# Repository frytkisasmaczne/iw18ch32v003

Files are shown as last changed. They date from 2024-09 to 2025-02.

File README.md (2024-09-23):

How to build PlatformIO based project
=====================================

1. [Install PlatformIO Core](https://docs.platformio.org/page/core.html)
2. Download [development platform with examples](https://github.com/Community-PIO-CH32V/platform-ch32v/archive/develop.zip)
3. Extract ZIP archive
4. Run these commands:

```shell
# Change directory to example
$ cd platform-ch32v/examples/blinky-ch32v003fun

# Build project
$ pio run

# Upload firmware
$ pio run --target upload

# Upload firmware for the specific environment
$ pio run -e ch32v003f4p6_evt_r0 --target upload

# Clean build files
$ pio run --target clean
```

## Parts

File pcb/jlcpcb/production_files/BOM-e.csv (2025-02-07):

Comment | Designator | Footprint | LCSC | Quantity
GND | J10 | PinHeader_1x01_P2.54mm_Vertical |  | 1
DC +5V | J8 | PinHeader_1x01_P2.54mm_Vertical |  | 1
DC 15GND | J7 | PinHeader_1x01_P2.54mm_Vertical |  | 1
DC +15V | J6 | PinHeader_1x01_P2.54mm_Vertical |  | 1
BC848 | Q13 | SOT-23 |  | 1
BC856 | Q20 | SOT-23 |  | 1
BC848 | Q23 | SOT-23 |  | 1
470uF 50V | C2 | CP_Radial_D13.0mm_P5.00mm |  | 1
4.7k | R62 | R_0201_0603Metric |  | 1
100 | R23 | R_0201_0603Metric |  | 1
47k | R40 | R_0201_0603Metric |  | 1
100 | R51 | R_0201_0603Metric |  | 1
100 | R11 | R_0201_0603Metric |  | 1
2k | R13 | R_0201_0603Metric |  | 1
BC848 | Q31 | SOT-23 |  | 1
BC848 | Q7 | SOT-23 |  | 1
BC856 | Q30 | SOT-23 |  | 1
4.7k | R58 | R_0201_0603Metric |  | 1
4.7k | R3 | R_0201_0603Metric |  | 1
BC856 | Q6 | SOT-23 |  | 1
Grids and Anodes | J1 | PinHeader_1x17_P2.54mm_Vertical |  | 1
74HC164 | U3 | SSOP-14_5.3x6.2mm_P0.65mm |  | 1
GPS Header | J9 | PinHeader_1x04_P2.54mm_Vertical |  | 1
100 | R55 | R_0201_0603Metric |  | 1
47k | R56 | R_0201_0603Metric |  | 1
4.7k | R38 | R_0201_0603Metric |  | 1
4.7k | R34 | R_0201_0603Metric |  | 1
BC856 | Q8 | SOT-23 |  | 1
4.7k | R14 | R_0201_0603Metric |  | 1
BC848 | Q33 | SOT-23 |  | 1
2k | R21 | R_0201_0603Metric |  | 1
2k | R41 | R_0201_0603Metric |  | 1
BC848 | Q15 | SOT-23 |  | 1
4.7k | R6 | R_0201_0603Metric |  | 1
2k | R9 | R_0201_0603Metric |  | 1
AC 15V | J3 | PinHeader_1x02_P2.54mm_Vertical |  | 1
BC856 | Q22 | SOT-23 |  | 1
BC856 | Q16 | SOT-23 |  | 1
2k | R37 | R_0201_0603Metric |  | 1
BC848 | Q1 | SOT-23 |  | 1
BC856 | Q26 | SOT-23 |  | 1
4.7k | R10 | R_0201_0603Metric |  | 1
47k | R60 | R_0201_0603Metric |  | 1
CH32V003 PROG | J2 | PinHeader_1x04_P2.54mm_Vertical |  | 1
BC856 | Q4 | SOT-23 |  | 1
BC848 | Q9 | SOT-23 |  | 1
BC856 | Q32 | SOT-23 |  | 1
2k | R5 | R_0201_0603Metric |  | 1
BC848 | Q19 | SOT-23 |  | 1
2k | R1 | R_0201_0603Metric |  | 1
100 | R39 | R_0201_0603Metric |  | 1
47k | R28 | R_0201_0603Metric |  | 1
4.7k | R42 | R_0201_0603Metric |  | 1
100 | R19 | R_0201_0603Metric |  | 1
BC856 | Q12 | SOT-23 |  | 1
47k | R36 | R_0201_0603Metric |  | 1
BC856 | Q34 | SOT-23 |  | 1
100 | R59 | R_0201_0603Metric |  | 1
2k | R33 | R_0201_0603Metric |  | 1
2k | R25 | R_0201_0603Metric |  | 1
100 | R31 | R_0201_0603Metric |  | 1
4.7k | R22 | R_0201_0603Metric |  | 1
100 | R15 | R_0201_0603Metric |  | 1
47k | R16 | R_0201_0603Metric |  | 1
47k | R68 | R_0201_0603Metric |  | 1
4.7k | R50 | R_0201_0603Metric |  | 1
4.7k | R30 | R_0201_0603Metric |  | 1
100 | R67 | R_0201_0603Metric |  | 1
100 | R7 | R_0201_0603Metric |  | 1
47k | R48 | R_0201_0603Metric |  | 1
100 | R27 | R_0201_0603Metric |  | 1
BC856 | Q28 | SOT-23 |  | 1
47k | R20 | R_0201_0603Metric |  | 1
47k | R8 | R_0201_0603Metric |  | 1
BC856 | Q24 | SOT-23 |  | 1
AC Filament Middle | J5 | PinHeader_1x01_P2.54mm_Vertical |  | 1
2k | R65 | R_0201_0603Metric |  | 1
100 | R2 | R_0201_0603Metric |  | 1
47k | R32 | R_0201_0603Metric |  | 1
BC848 | Q5 | SOT-23 |  | 1
1N4007 | D1 | D_DO-41_SOD81_P10.16mm_Horizontal |  | 1
BC848 | Q29 | SOT-23 |  | 1
47k | R52 | R_0201_0603Metric |  | 1
100 | R43 | R_0201_0603Metric |  | 1
47k | R4 | R_0201_0603Metric |  | 1
2k | R61 | R_0201_0603Metric |  | 1
2k | R49 | R_0201_0603Metric |  | 1
47k | R44 | R_0201_0603Metric |  | 1
BC848 | Q25 | SOT-23 |  | 1
100 | R63 | R_0201_0603Metric |  | 1
100 | R47 | R_0201_0603Metric |  | 1
47uF 100V | C1 | CP_Radial_D10.0mm_P5.00mm |  | 1
BC848 | Q11 | SOT-23 |  | 1
AC 27V | J4 | PinHeader_1x02_P2.54mm_Vertical |  | 1
BC856 | Q18 | SOT-23 |  | 1
74HC164 | U1 | SSOP-14_5.3x6.2mm_P0.65mm |  | 1
BC848 | Q17 | SOT-23 |  | 1
2k | R53 | R_0201_0603Metric |  | 1
4.7k | R54 | R_0201_0603Metric |  | 1
CH32V003FxPx | U2 | TSSOP-20_4.4x6.5mm_P0.65mm |  | 1
2k | R17 | R_0201_0603Metric |  | 1
BC856 | Q2 | SOT-23 |  | 1
4.7k | R18 | R_0201_0603Metric |  | 1
47k | R12 | R_0201_0603Metric |  | 1
2k | R57 | R_0201_0603Metric |  | 1
4.7k | R26 | R_0201_0603Metric |  | 1
BC848 | Q21 | SOT-23 |  | 1
BC848 | Q3 | SOT-23 |  | 1
2k | R29 | R_0201_0603Metric |  | 1
BC856 | Q10 | SOT-23 |  | 1
GBU4M | D2 | Diode_Bridge_Vishay_GBU |  | 1
BC856 | Q14 | SOT-23 |  | 1
4.7k | R46 | R_0201_0603Metric |  | 1
4.7k | R66 | R_0201_0603Metric |  | 1
100 | R35 | R_0201_0603Metric |  | 1
2k | R45 | R_0201_0603Metric |  | 1
47k | R24 | R_0201_0603Metric |  | 1
BC848 | Q27 | SOT-23 |  | 1
47k | R64 | R_0201_0603Metric |  | 1
GBU4M | D3 | Diode_Bridge_Vishay_GBU |  | 1

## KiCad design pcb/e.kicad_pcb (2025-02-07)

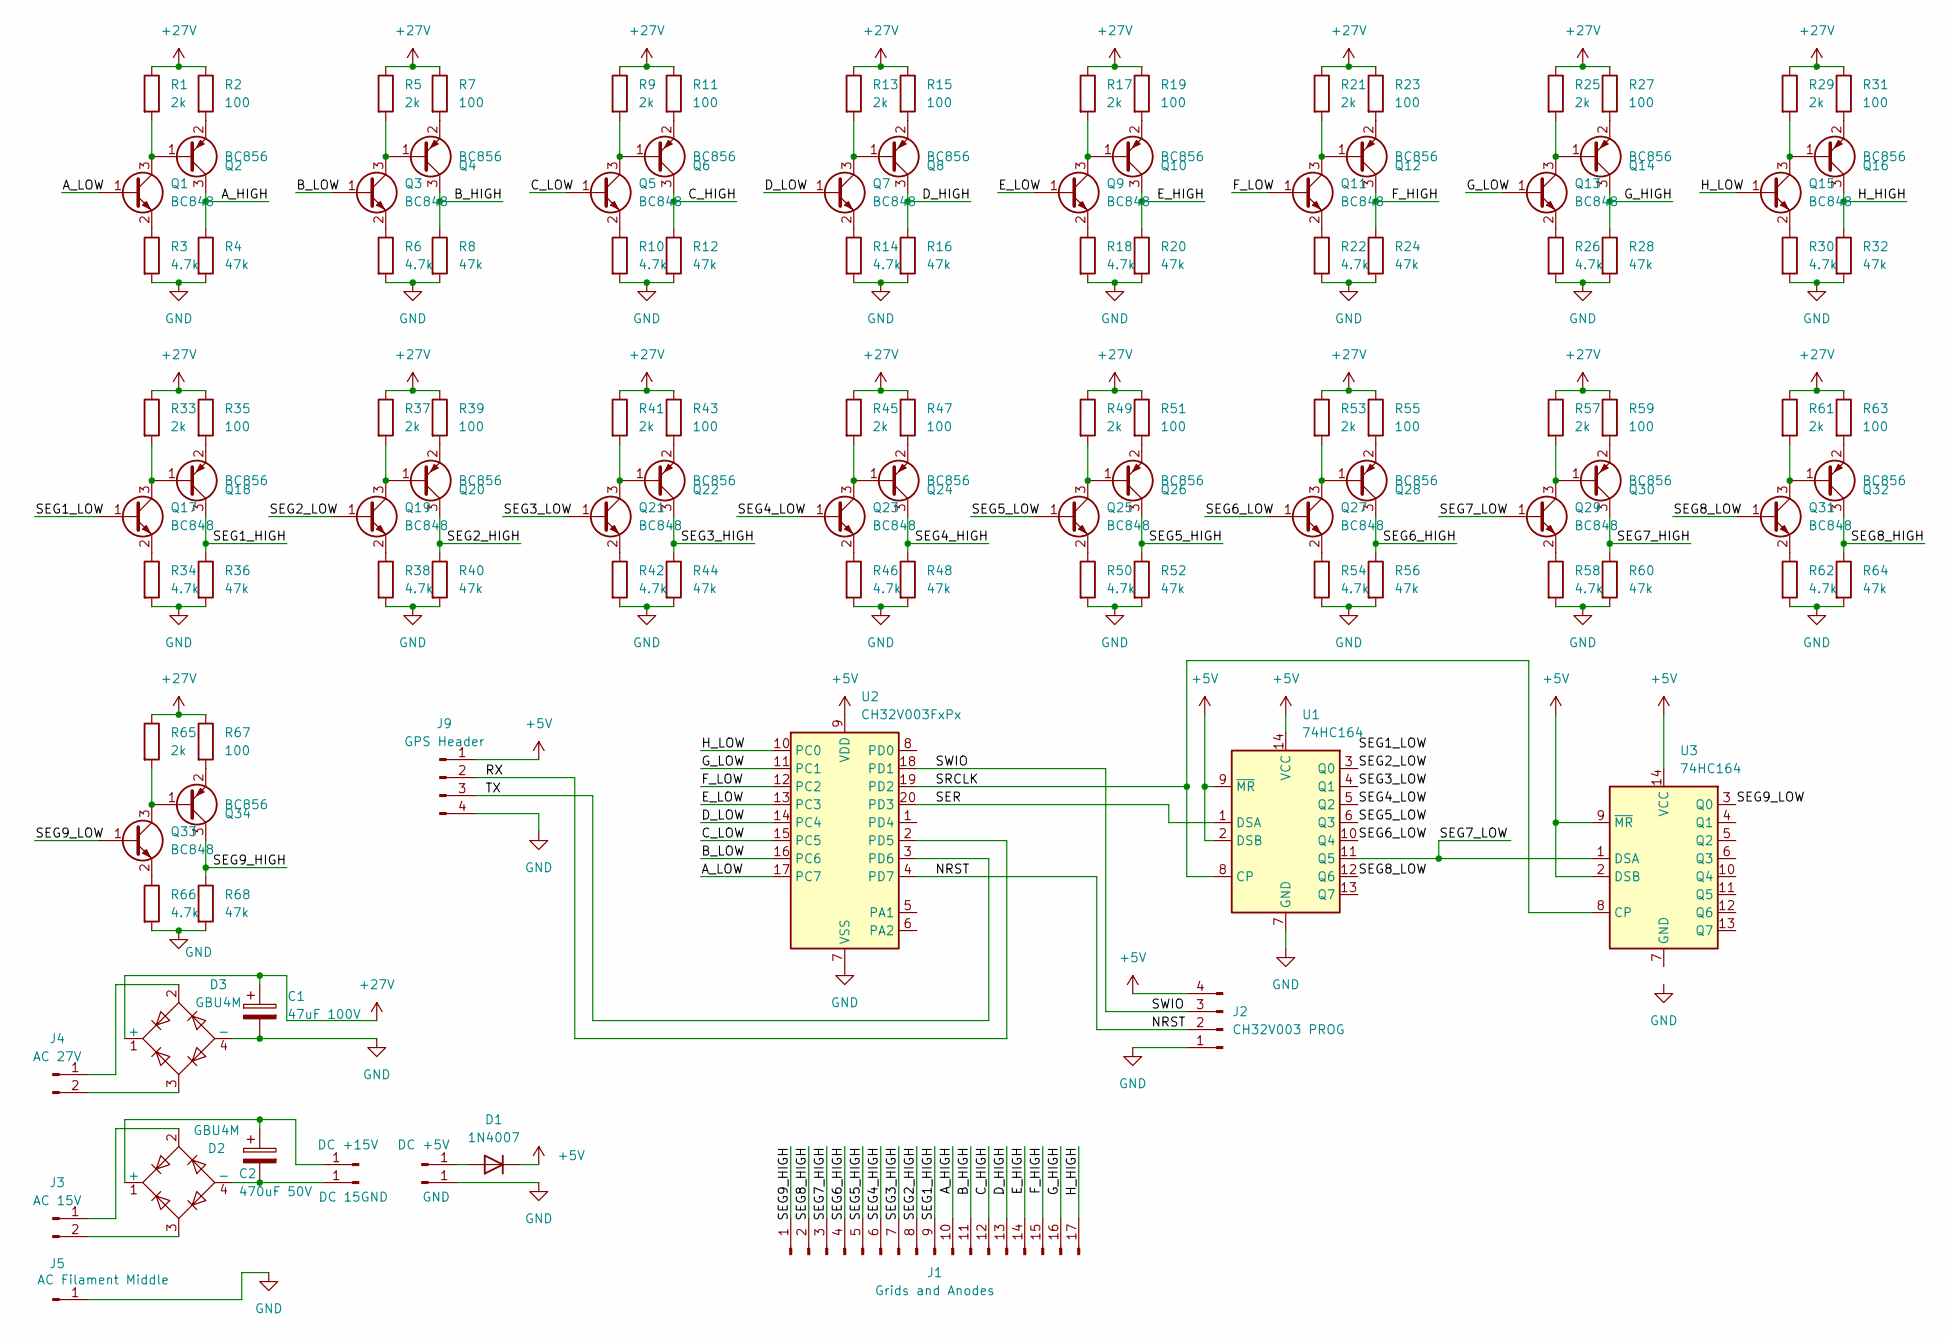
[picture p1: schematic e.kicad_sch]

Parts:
C1: 47uF 100V; CP_Radial_D10.0mm_P5.00mm
C2: 470uF 50V; CP_Radial_D13.0mm_P5.00mm
D1: 1N4007; D_DO-41_SOD81_P10.16mm_Horizontal
D2, D3: GBU4M; Diode_Bridge_Vishay_GBU
J1: Grids and Anodes; PinHeader_1x17_P2.54mm_Vertical
J2: CH32V003 PROG; PinHeader_1x04_P2.54mm_Vertical
J3: AC 15V; PinHeader_1x02_P2.54mm_Vertical
J4: AC 27V; PinHeader_1x02_P2.54mm_Vertical
J5: AC Filament Middle; PinHeader_1x01_P2.54mm_Vertical
J6: DC +15V; PinHeader_1x01_P2.54mm_Vertical
J7: DC 15GND; PinHeader_1x01_P2.54mm_Vertical
J8: DC +5V; PinHeader_1x01_P2.54mm_Vertical
J9: GPS Header; PinHeader_1x04_P2.54mm_Vertical
J10: GND; PinHeader_1x01_P2.54mm_Vertical
Q1, Q3, Q5, Q7, Q9, Q11, Q13, Q15, Q17, Q19, Q21, Q23, Q25, Q27, Q29, Q31, Q33: BC848; SOT-23
Q2, Q4, Q6, Q8, Q10, Q12, Q14, Q16, Q18, Q20, Q22, Q24, Q26, Q28, Q30, Q32, Q34: BC856; SOT-23
R1, R5, R9, R13, R17, R21, R25, R29, R33, R37, R41, R45, R49, R53, R57, R61, R65: 2k; R_0201_0603Metric
R2, R7, R11, R15, R19, R23, R27, R31, R35, R39, R43, R47, R51, R55, R59, R63, R67: 100; R_0201_0603Metric
R3, R6, R10, R14, R18, R22, R26, R30, R34, R38, R42, R46, R50, R54, R58, R62, R66: 4.7k; R_0201_0603Metric
R4, R8, R12, R16, R20, R24, R28, R32, R36, R40, R44, R48, R52, R56, R60, R64, R68: 47k; R_0201_0603Metric
U1, U3: 74HC164; SSOP-14_5.3x6.2mm_P0.65mm
U2: CH32V003FxPx; TSSOP-20_4.4x6.5mm_P0.65mm

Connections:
+5V: D1.1 (K), J2.4, J9.1, U1.2 (DSB), U1.9 (~MR), U1.14 (VCC), U2.9 (VDD), U3.2 (DSB), U3.9 (~MR), U3.14 (VCC)
+27V: C1.1, D3.1 (+), R1.1, R2.1, R5.1, R7.1, R9.1, R11.1, R13.1, R15.1, R17.1, R19.1, R21.1, R23.1, R25.1, R27.1, R29.1, R31.1, R33.1, R35.1, R37.1, R39.1, R41.1, R43.1, R45.1, R47.1, R49.1, R51.1, R53.1, R55.1, R57.1, R59.1, R61.1, R63.1, R65.1, R67.1
/A_HIGH: J1.10, Q2.3 (C), R4.1
/A_LOW: Q1.1 (B), U2.17 (PC7)
/B_HIGH: J1.11, Q4.3 (C), R8.1
/B_LOW: Q3.1 (B), U2.16 (PC6)
/C_HIGH: J1.12, Q6.3 (C), R12.1
/C_LOW: Q5.1 (B), U2.15 (PC5)
/D_HIGH: J1.13, Q8.3 (C), R16.1
/D_LOW: Q7.1 (B), U2.14 (PC4)
/E_HIGH: J1.14, Q10.3 (C), R20.1
/E_LOW: Q9.1 (B), U2.13 (PC3)
/F_HIGH: J1.15, Q12.3 (C), R24.1
/F_LOW: Q11.1 (B), U2.12 (PC2)
/G_HIGH: J1.16, Q14.3 (C), R28.1
/G_LOW: Q13.1 (B), U2.11 (PC1)
/H_HIGH: J1.17, Q16.3 (C), R32.1
/H_LOW: Q15.1 (B), U2.10 (PC0)
/NRST: J2.2, U2.4 (PD7)
/RX: J9.2, U2.2 (PD5)
/SEG1_HIGH: J1.9, Q18.3 (C), R36.1
/SEG1_LOW: Q17.1 (B)
/SEG2_HIGH: J1.8, Q20.3 (C), R40.1
/SEG2_LOW: Q19.1 (B), U1.3 (Q0)
/SEG3_HIGH: J1.7, Q22.3 (C), R44.1
/SEG3_LOW: Q21.1 (B), U1.4 (Q1)
/SEG4_HIGH: J1.6, Q24.3 (C), R48.1
/SEG4_LOW: Q23.1 (B), U1.5 (Q2)
/SEG5_HIGH: J1.5, Q26.3 (C), R52.1
/SEG5_LOW: Q25.1 (B), U1.6 (Q3)
/SEG6_HIGH: J1.4, Q28.3 (C), R56.1
/SEG6_LOW: Q27.1 (B), U1.10 (Q4)
/SEG7_HIGH: J1.3, Q30.3 (C), R60.1
/SEG7_LOW: Q29.1 (B), U1.11 (Q5), U3.1 (DSA)
/SEG8_HIGH: J1.2, Q32.3 (C), R64.1
/SEG8_LOW: Q31.1 (B), U1.12 (Q6)
/SEG9_HIGH: J1.1, Q34.3 (C), R68.1
/SEG9_LOW: Q33.1 (B), U3.3 (Q0)
/SER: U1.1 (DSA), U2.20 (PD3)
/SRCLK: U1.8 (CP), U2.19 (PD2), U3.8 (CP)
/SWIO: J2.3, U2.18 (PD1)
/TX: J9.3, U2.3 (PD6)
GND: C1.2, D3.4 (-), J2.1, J5.1, J9.4, J10.1, R3.2, R4.2, R6.2, R8.2, R10.2, R12.2, R14.2, R16.2, R18.2, R20.2, R22.2, R24.2, R26.2, R28.2, R30.2, R32.2, R34.2, R36.2, R38.2, R40.2, R42.2, R44.2, R46.2, R48.2, R50.2, R52.2, R54.2, R56.2, R58.2, R60.2, R62.2, R64.2, R66.2, R68.2, U1.7 (GND), U2.7 (VSS)
unnamed: D1.2 (A), J8.1
unnamed: C2.1, D2.1 (+), J6.1
unnamed: C2.2, D2.4 (-), J7.1
unnamed: D2.2, J3.1
unnamed: D2.3, J3.2
unnamed: D3.2, J4.1
unnamed: D3.3, J4.2
unnamed: Q1.3 (C), Q2.1 (B), R1.2
unnamed: Q1.2 (E), R3.1
unnamed: Q2.2 (E), R2.2
unnamed: Q3.3 (C), Q4.1 (B), R5.2
unnamed: Q3.2 (E), R6.1
unnamed: Q4.2 (E), R7.2
unnamed: Q5.3 (C), Q6.1 (B), R9.2
unnamed: Q5.2 (E), R10.1
unnamed: Q6.2 (E), R11.2
unnamed: Q7.3 (C), Q8.1 (B), R13.2
unnamed: Q7.2 (E), R14.1
unnamed: Q8.2 (E), R15.2
unnamed: Q9.2 (E), R18.1
unnamed: Q9.3 (C), Q10.1 (B), R17.2
unnamed: Q10.2 (E), R19.2
unnamed: Q11.3 (C), Q12.1 (B), R21.2
unnamed: Q11.2 (E), R22.1
unnamed: Q12.2 (E), R23.2
unnamed: Q13.3 (C), Q14.1 (B), R25.2
unnamed: Q13.2 (E), R26.1
unnamed: Q14.2 (E), R27.2
unnamed: Q15.3 (C), Q16.1 (B), R29.2
unnamed: Q15.2 (E), R30.1
unnamed: Q16.2 (E), R31.2
unnamed: Q17.3 (C), Q18.1 (B), R33.2
unnamed: Q17.2 (E), R34.1
unnamed: Q18.2 (E), R35.2
unnamed: Q19.3 (C), Q20.1 (B), R37.2
unnamed: Q19.2 (E), R38.1
unnamed: Q20.2 (E), R39.2
unnamed: Q21.3 (C), Q22.1 (B), R41.2
unnamed: Q21.2 (E), R42.1
unnamed: Q22.2 (E), R43.2
unnamed: Q23.3 (C), Q24.1 (B), R45.2
unnamed: Q23.2 (E), R46.1
unnamed: Q24.2 (E), R47.2
unnamed: Q25.3 (C), Q26.1 (B), R49.2
unnamed: Q25.2 (E), R50.1
unnamed: Q26.2 (E), R51.2
unnamed: Q27.3 (C), Q28.1 (B), R53.2
unnamed: Q27.2 (E), R54.1
unnamed: Q28.2 (E), R55.2
unnamed: Q29.3 (C), Q30.1 (B), R57.2
unnamed: Q29.2 (E), R58.1
unnamed: Q30.2 (E), R59.2
unnamed: Q31.3 (C), Q32.1 (B), R61.2
unnamed: Q31.2 (E), R62.1
unnamed: Q32.2 (E), R63.2
unnamed: Q33.3 (C), Q34.1 (B), R65.2
unnamed: Q33.2 (E), R66.1
unnamed: Q34.2 (E), R67.2

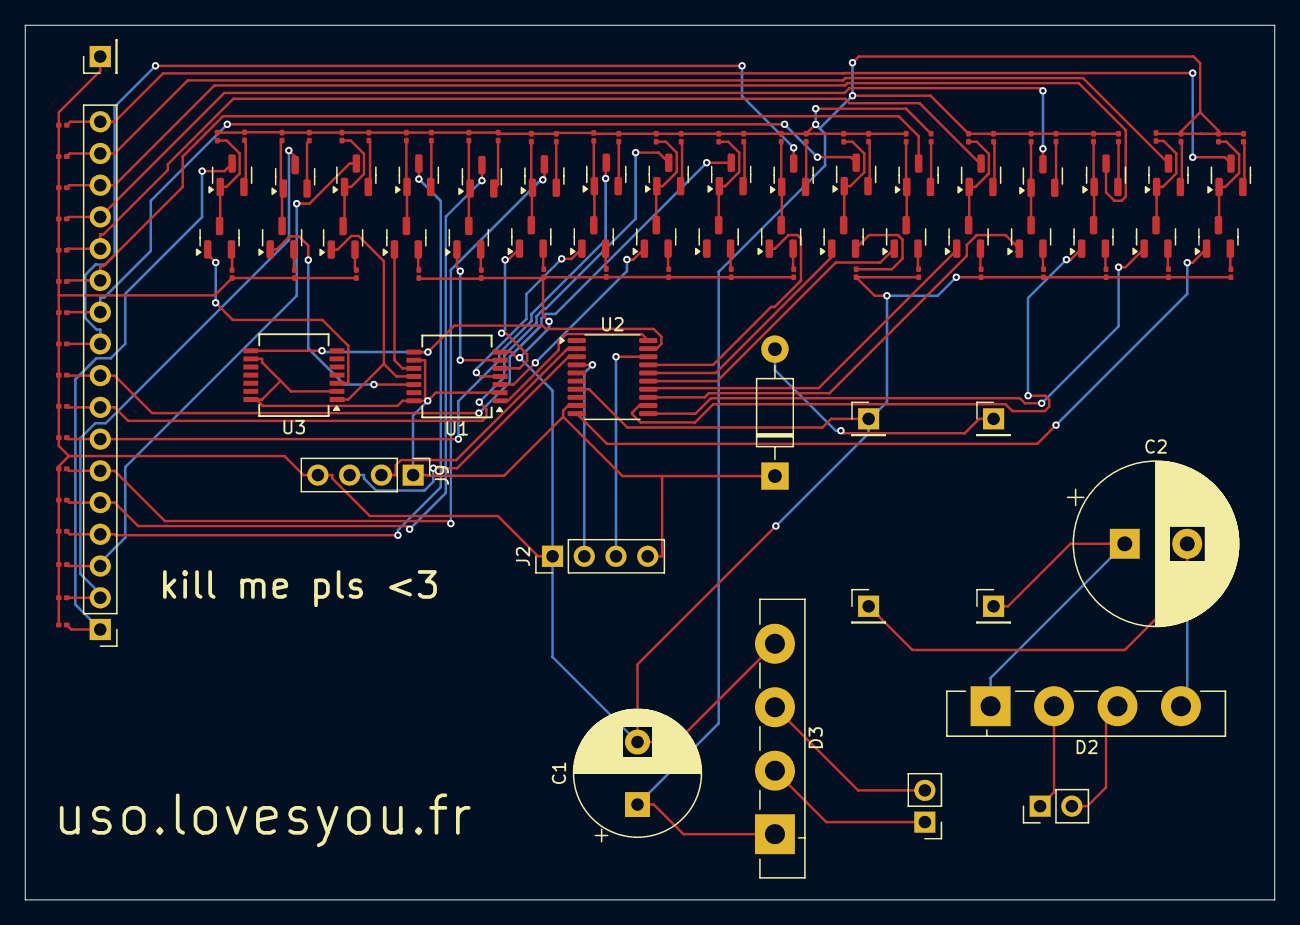
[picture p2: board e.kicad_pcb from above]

Board: 2 copper layers, 100.0 x 70.0 mm, 120 parts (0 on the bottom side), 100 nets.

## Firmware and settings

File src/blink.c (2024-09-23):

#include "ch32v003fun.h"
#include <stdio.h>

// #ifdef funDigitalWrite
// 	#undef funDigitalWrite
// 	#define funDigitalWrite( pin, value ) { value ? (GpioOf( pin )->BSHR = 1<<((!(value))*16 + ((pin) & 0xf))) : (GpioOf( pin )->BCR = 1<<((!(value))*16 + ((pin) & 0xf))); }

// #endif

#define GPS_UART_BR 9600
#define NINEHUNDREDTH_OF_SECOND Ticks_from_Ms(1)
#define A_SECOND Ticks_from_Ms(1000)
#define FIVE_SECONDS Ticks_from_Ms(5000)
#define HUNDRED_MS Ticks_from_Ms(100)
#define THIRTY_SECONDS Ticks_from_Ms(1000*30)
uint32_t last_second_ticks = 0;
uint32_t next_parse_time = 0;
uint32_t epoch = 0;
uint8_t hours = 21;
uint8_t minutes = 37;
uint8_t seconds = 0;
const char GPRMC[] = "$GPRMC,";
#define STRLEN(s) (sizeof(s)/sizeof(s[0])-1)

typedef struct bank_and_shift{
	GPIO_TypeDef *bank;
	uint8_t shift;
} bank_and_shift_t;

// const bank_and_shift_t pinsmap[12] = {
// 	{ .bank = GPIOC, .shift = 2 },
// 	{ .bank = GPIOD, .shift = 4 },
// 	{ .bank = GPIOD, .shift = 3 },
// 	{ .bank = GPIOD, .shift = 2 },
// 	{ .bank = GPIOD, .shift = 0 },
// 	{ .bank = GPIOC, .shift = 7 },
// 	{ .bank = GPIOC, .shift = 6 },
// 	{ .bank = GPIOC, .shift = 5 },
// 	{ .bank = GPIOC, .shift = 0 },

// 	{ .bank = GPIOC, .shift = 3 },
// 	{ .bank = GPIOC, .shift = 4 },
// 	{ .bank = GPIOC, .shift = 1 },
// };

// const int segments[12] = {
// 	PC2,PD4,PD3,PD2,PD0,PC7,PC6,PC5,PC0, /* seg a-h */
// 	PC3,PC4,PC1, /* SRCLK, SER, OE */
// };
const int segments[12] = {
	PC0,PC1,PC2,PC3,PC4,PC5,PC6,PC7, /* seg a-h */
	PD2,PD3, /* SRCLK, SER */
};

const uint8_t sevensegmap[13] = {
	0b11111100, // 0
	0b01100000, // 1
	0b11011010, // 2
	0b11110010, // 3
	0b01100110, // 4
	0b10110110, // 5
	0b10111110, // 6
	0b11100000, // 7
	0b11111110, // 8
	0b11110110, // 9
	0b00000001, // . = 10
	0b00000010, // - = 11
	0b00000000, // blank = 12
};

uint8_t digits[9] = {
	12,12,12,12,12,2,1,3,7,
};

#define UART_BUF_LEN 255
uint8_t uart_data[UART_BUF_LEN] = {0};

void increment_time()
{
	seconds++;
	if (seconds >= 60) {
		seconds -= 60;
		minutes++;
	}
	if (minutes >= 60) {
		minutes -= 60;
		hours++;
	}
	if (hours > 24) {
		hours -= 24;
	}
}

void display_time()
{
	digits[0] = 12;
	digits[1] = hours/10;
	digits[2] = (hours%10);
	digits[3] = minutes/10;
	digits[4] = (minutes%10);
	digits[5] = seconds/10;
	digits[6] = (seconds%10);
	digits[7] = 12;
	digits[8] = 12;
}

int parse_time() {
	uint8_t chars = 0;

	for (int i=0; i < UART_BUF_LEN; i++)
	{
		uint32_t j = ((UART_BUF_LEN - DMA1_Channel5->CNTR) + i) % UART_BUF_LEN;
		// printf("%c", uart_data[j]);
		if (chars < STRLEN(GPRMC))
		{
			// printf("a(%d)", chars);
			if (GPRMC[chars] == uart_data[j]) {
				chars++;
			}
			else {
				chars = 0;
			}
		}
		else if (chars < STRLEN(GPRMC)+6)
		{
			// printf("b");
			if (uart_data[j] >= '0' && uart_data[j] <= '9')
			{
				chars++;
			}
			else {
				chars = 0;
			}
		}
		else
		{
			// printf("c");
			if (chars == STRLEN(GPRMC)+6 && uart_data[j] == '.')
			{
				hours = 10*(uart_data[ ((UART_BUF_LEN+j-6) % UART_BUF_LEN) ]-'0') + (uart_data[ ((UART_BUF_LEN+j-5) % UART_BUF_LEN) ]-'0');
				minutes = 10*(uart_data[ ((UART_BUF_LEN+j-4) % UART_BUF_LEN) ]-'0') + (uart_data[ ((UART_BUF_LEN+j-3) % UART_BUF_LEN) ]-'0');
				seconds = 10*(uart_data[ ((UART_BUF_LEN+j-2) % UART_BUF_LEN) ]-'0') + (uart_data[ ((UART_BUF_LEN+j-1) % UART_BUF_LEN) ]-'0');
				return 1;
			}
		}
	}
	return 0;
}

// void bDigitalWrite(uint8_t digit, uint8_t state)
// {
	
// 	if (state)
// 	{
// 		pinsmap[digit].bank->BSHR |= 1 << pinsmap[digit].shift;
// 	} else
// 	{
// 		pinsmap[digit].bank->BCR |= 1 << pinsmap[digit].shift;
// 	}

// }

void uart_setup()
{
	// enable uart
	RCC->APB2PCENR |= RCC_APB2Periph_GPIOD | RCC_APB2Periph_USART1;
	// Push-Pull, 10MHz Output on D5, with AutoFunction
	GPIOD->CFGLR |= ~(0xf<<(4*6));
	GPIOD->CFGLR |= (GPIO_Speed_10MHz | GPIO_CNF_OUT_PP_AF)<<(4*6);

	USART1->CTLR1 = USART_WordLength_8b | USART_Parity_No | USART_Mode_Rx;
	USART1->CTLR2 = USART_StopBits_1;
	// enable dma rx
	USART1->CTLR3 = USART_DMAReq_Rx;
	// set baudrate
	USART1->BRR = (FUNCONF_SYSTEM_CORE_CLOCK + GPS_UART_BR/2) / GPS_UART_BR;
	// enable uart
	USART1->CTLR1 |= CTLR1_UE_Set;

	// dma
	RCC->AHBPCENR = RCC_AHBPeriph_SRAM | RCC_AHBPeriph_DMA1;
	DMA1_Channel5->CFGR &= ~DMA_CFGR1_EN;
	DMA1_Channel5->PADDR = (uint32_t)&USART1->DATAR;
	DMA1_Channel5->CFGR = DMA_CFGR1_MINC | DMA_CFGR1_CIRC;
	DMA1_Channel5->CNTR = UART_BUF_LEN;
	DMA1_Channel5->MADDR = (uint32_t)uart_data;
	NVIC_EnableIRQ(DMA1_Channel5_IRQn);
	DMA1_Channel5->CFGR |= DMA_CFGR1_EN;
}

void interrupt_setup()
{
	/* clear systick settings */
	SysTick->CTLR = 0;

	NVIC_EnableIRQ(SysTicK_IRQn);
	/* set tick interval */
	SysTick->CMP = NINEHUNDREDTH_OF_SECOND-1;	
	/* reset count */
	SysTick->CNT = 0;
	// systick_cnt = 0;
	/* enable systick counter, irq, hclk/1 */
	SysTick->CTLR = SYSTICK_CTLR_STE | SYSTICK_CTLR_STIE | SYSTICK_CTLR_STCLK;
}

uint8_t idig = 0;

void SysTick_Handler(void) __attribute__((interrupt));
void SysTick_Handler(void)
{
	/* set new interrupt */
	SysTick->CMP = SysTick->CNT + NINEHUNDREDTH_OF_SECOND;
	/* clear irq */
	SysTick->SR = 0;

	/* do one digit */
	/* at the end of digits sweep send a single pulse to the shift register */
	if (idig == 8) {
		/* set SER */
		GPIOD->BSHR |= 1 << 3;
	} else {
		GPIOD->BCR |= 1 << 3;
	}
	/* clear segments */
	GPIOC->BCR = 0xff;
	/* tick SRCLK */
	GPIOD->BSHR |= 1 << 2;
	GPIOD->BCR |= 1 << 2;
	/* set segments */
	GPIOC->BSHR = sevensegmap[digits[idig]] | ((idig == 2 || idig == 4) ? 1 : 0);
	/* increment digit */
	idig = (idig+1)%9;
}

int main()
{
	SystemInit();
	uart_setup();

	printf("yukkuri\n");

	// Enable GPIOs
	funGpioInitAll();
	
	// set all gpio in segments array as output
	for (uint8_t i=0; i<11; i++)
	{
		funPinMode( segments[i], GPIO_Speed_10MHz | GPIO_CNF_OUT_PP );
	}

	interrupt_setup();
	next_parse_time = SysTick->CNT + FIVE_SECONDS;
	
	GPIOC->BSHR = 0xff;

	printf("nijika wa daisuki\n");

	display_time();
	while (1) {
		/* move time forward */
		if ( (SysTick->CNT - last_second_ticks) > A_SECOND )
		{
			increment_time();
			display_time();
			last_second_ticks += A_SECOND;
		}
		if ( (int32_t)(SysTick->CNT - next_parse_time) > 0)
		{
			if (parse_time()) {
				next_parse_time = SysTick->CNT + FIVE_SECONDS;
			}
			else {
				/* more frequent spamming since 255 dma buffer fits only a part of the messages sent every second*/
				next_parse_time = SysTick->CNT + HUNDRED_MS;
			}
			printf("ua%drt %s lol\n", DMA1_Channel5->CNTR, uart_data);
		}
		
		
		
	}




	// while(1)
	// {
	// 	for (uint8_t idig = 0; idig < 9; idig++)
	// 	{
	// 		// // disable digit
	// 		// funDigitalWrite( segments[(9+idig-1) % 9], 0);
	// 		// if ( idig != 0 )
	// 		bDigitalWrite( (9+idig-1) % 9, 0);
	// 		// disable OE
	// 		bDigitalWrite(11, 1);
	// 		// update shift reg
	// 		for (uint8_t i = 0; i < 8; i++) {
	// 			if ( (sevensegmap[ digits[idig] ] >> i) & 1 )
	// 			{
	// 				// funDigitalWrite(PC4, 1);
	// 				bDigitalWrite(10, 1);
	// 			} else
	// 			{
	// 				// funDigitalWrite(PC4, 0);
	// 				bDigitalWrite(10, 0);
	// 			}
	// 			// funDigitalWrite(PC3, 1);
	// 			bDigitalWrite(9, 1);
	// 			// Delay_Us( 1 );
	// 			// funDigitalWrite(PC3, 0);
	// 			bDigitalWrite(9, 0);
	// 			// Delay_Us( 1 );
	// 			// Delay_Ms( 10 );
	// 		}
	// 		// funDigitalWrite(PC3, 1);
	// 		bDigitalWrite(9, 1);
	// 		// Delay_Us( 1 );
	// 		// funDigitalWrite(PC3, 0);
	// 		bDigitalWrite(9, 0);


	// 		if ( idig != 8 )
	// 		{
	// 			// funDigitalWrite(segments[idig], 1);
	// 			bDigitalWrite(idig, 1);
	// 		}
	// 		// enable OE
	// 		bDigitalWrite(11, 0);
	// 		// // select digit
	// 		// set_digit(idig, 1);
			

	// 		// printf("nijika wa daisuki ");
	// 		// for (uint8_t i=0;i<9;i++)
	// 		// {
	// 		// 	printf(" %d", digits[i]);
	// 		// }
	// 		// printf("\n");
	// 		// digits[(idig+1)%9] = 9;
	// 		Delay_Ms( 1 );
			
	// 		// if ((SysTick->CNT - last_second_ticks) > THIRTY_SECONDS)
	// 		// {
	// 		// 	printf("uart %s lol\n", uart_data);
	// 		// 	increment_time();
	// 		// 	display_time();
	// 		// 	last_second_ticks += THIRTY_SECONDS;
	// 		// }
	// 	} /* for 9 times a second - every digit */

	// 	// any work goes here or at the end of for
	// 	// uint8_t temp = digits[8];
	// 	// for (int i=0; i<8; i++)
	// 	// {
	// 	// 	digits[8-i] = digits[7-i];
	// 	// }
	// 	// digits[0] = temp;
		

	// }

}




// void SysTick_Handler(void) __attribute__((interrupt));
// void SysTick_Handler(void)
// {
// 	uint32_t tenter = SysTick->CNT;

// 	// printf("nijika wa daisuki\n");
// 	/* set new interrupt*/
// 	SysTick->CMP = SysTick->CNT + NINEHUNDREDTH_OF_SECOND;
// 	/* clear irq */
// 	SysTick->SR = 0;

// 	/* do one digit */
// 	/* disable digit */
// 	bDigitalWrite( (9+idig-1) % 9, 0);
// 	// /* disable OE */
// 	// bDigitalWrite(11, 1);
// 	for (uint8_t i = 0; i < 8; i++) {
// 		if ( (sevensegmap[ digits[idig] ] >> i) & 1 ) {
// 			bDigitalWrite(10, 1);
// 		} else {
// 			bDigitalWrite(10, 0);
// 		}
// 		/* tick */
// 		bDigitalWrite(9, 1);
// 		bDigitalWrite(9, 0);
// 	}
// 	/* tick */
// 	bDigitalWrite(9, 1);
// 	bDigitalWrite(9, 0);
// 	/* enable digit */
// 	bDigitalWrite(idig, 1);
// 	// /* enable OE */
// 	// bDigitalWrite(11, 0);
// 	idig = (idig+1)%9;

// 	tenter = (int32_t)(SysTick->CNT - tenter);
// 	printf("time %d\n", tenter);
// }
